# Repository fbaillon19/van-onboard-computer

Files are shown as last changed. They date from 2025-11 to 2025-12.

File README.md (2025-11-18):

# 🚐 VOBC - Van Onboard Computer

**V**an **O**nboard **B**oard **C**omputer - Système de monitoring et de gestion pour fourgon aménagé.





## 📋 Présentation

Le VOBC est un ordinateur de bord complet pour fourgon aménagé permettant de :
- 🌡️ Monitorer température intérieure/extérieure et humidité
- ⚡ Gérer l'énergie (batterie, panneaux solaires, consommation)
- ⚠️ Détecter les dangers (CO, fuite de gaz)
- 📊 Mesurer l'horizontalité pour stationnement
- 💧 Surveiller les niveaux d'eau
- 🔔 Alertes sonores et visuelles configurables
- 📈 Historique des données sur carte SD

## 🎯 Fonctionnalités

### Phase 1 - INDISPENSABLE ✅
- [x] Température intérieure + humidité (BME280)
- [x] Température extérieure (DS18B20)
- [x] Détection CO (MQ-7)
- [x] Détection gaz GPL (MQ-2)
- [x] Monitoring batterie (INA226)
- [x] Horizontalité 3 axes (MPU6050)
- [x] Détection ouverture portes (Reed Switch)
- [x] Alertes visuelles (LED RGB) et sonores (Buzzer)
- [x] Affichage LCD 20x4 I2C
- [x] Navigation par encodeur rotatif

### Phase 2 - IMPORTANTE 🔶
- [ ] Niveaux réservoirs eau (HC-SR04)
- [ ] Ventilation automatique (Module relais)
- [ ] Détecteur de mouvement (PIR)
- [ ] Monitoring panneaux solaires (INA226 #2)
- [ ] Éclairage automatique (LDR)

### Phase 3 - MOYENNE 🔹
- [ ] Horodatage (RTC DS3231)
- [ ] Historique données (Module SD)
- [ ] Orientation/boussole (HMC5883L)
- [ ] Prévision solaire algorithmique
- [ ] Interface Web/Bluetooth (optionnel)

## 🔧 Matériel

### Contrôleur
- Arduino MEGA 2560 R3

### Capteurs Phase 1
- BME280 (I2C) - Température + Humidité + Pression
- INA226 (I2C) - Courant/Tension batterie
- MPU6050 (I2C) - Gyroscope + Accéléromètre
- MQ-7 (Analogique) - Détecteur CO
- MQ-2 (Analogique) - Détecteur GPL/Butane
- DS18B20 (One-Wire) - Température extérieure étanche
- Reed Switch - Détection portes

### Interface
- LCD 20x4 avec module I2C
- Encodeur rotatif KY-040
- LED RGB + Buzzer piézo

### Alimentation
- Convertisseur DC-DC 12V → 5V (LM2596/MP1584) 3A min

Voir [HARDWARE.md](docs/HARDWARE.md) pour détails complets.

## 📁 Structure du projet

```
.
├── README.md                    # Ce fichier
├── LICENSE                      # Licence MIT
├── CHANGELOG.md                 # Historique des versions
├── docs/                        # Documentation
│   ├── HARDWARE.md             # Schémas et câblage
│   ├── SOFTWARE.md             # Architecture logicielle
│   ├── CONFIGURATION.md        # Configuration système
│   ├── INSTALL.md              # Guide d'installation
│   └── images/                 # Schémas et photos
├── firmware/                    # Code Arduino
│   └── van_onboard_computer/
│       ├── van_onboard_computer.ino  # Fichier principal
│       ├── config.h                   # Configuration
│       └── *.cpp/*.h                  # Modules
├── hardware/                    # Fichiers matériels
│   ├── schematics/             # Schémas électriques
│   ├── pcb/                    # PCB (phase finale)
│   └── datasheets/             # Datasheets composants
├── testing/                     # Tests unitaires
│   ├── test_codes/             # Codes de test capteurs
│   └── testing_README.md       # Guide de test
└── tools/                       # Outils et scripts
    └── scripts/                # Scripts utilitaires
```

## 🚀 Installation rapide

### Prérequis
- Arduino IDE 2.x
- Librairies (voir [INSTALL.md](docs/INSTALL.md))

### Étapes
```bash
# Cloner le repo
git clone https://github.com/[votre-username]/van-onboard-computer.git
cd van-onboard-computer

# Installer les librairies nécessaires
# (voir docs/INSTALL.md)

# Ouvrir le firmware
# Arduino IDE: Ouvrir firmware/van_onboard_computer/van_onboard_computer.ino
# PlatformIO: Ouvrir le dossier dans VS Code

# Configurer dans config.h
# Compiler et uploader sur Arduino MEGA
```

## 📚 Documentation

- [Guide matériel](docs/HARDWARE.md) - Schémas de câblage complets
- [Architecture logicielle](docs/SOFTWARE.md) - Structure du code
- [Configuration](docs/CONFIGURATION.md) - Paramétrage système
- [Installation](docs/INSTALL.md) - Guide d'installation pas à pas
- [Tests](testing/testing_README.md) - Procédures de test

## 🧪 Tests

Chaque capteur dispose de son code de test unitaire dans `testing/test_codes/`. Voir [testing_README.md](testing/testing_README.md) pour la procédure complète.

## 🤝 Contribution

Les contributions sont bienvenues ! 

1. Fork le projet
2. Créer une branche (`git checkout -b feature/amelioration`)
3. Commit (`git commit -am 'Ajout fonctionnalité'`)
4. Push (`git push origin feature/amelioration`)
5. Créer une Pull Request

## 📝 Changelog

Voir [CHANGELOG.md](CHANGELOG.md) pour l'historique des versions.

## 📄 Licence

Ce projet est sous licence MIT - voir [LICENSE](LICENSE) pour plus de détails.

## 👤 Auteur

**Frédéric BAILLON**
- GitHub: [@fbaillon19](https://github.com/fbaillon19)

## 🙏 Remerciements

- Communauté Arduino
- Fabricants de capteurs (Bosch, Texas Instruments, etc.)
- Tous les contributeurs du projet

## 📸 Galerie

_Photos à venir lors de l'installation..._

---

⭐ Si ce projet vous aide, n'hésitez pas à lui donner une étoile !

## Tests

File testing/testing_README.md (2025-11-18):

# Guide de test VOBC

## 📋 Présentation

Ce dossier contient tous les codes de test unitaires pour valider chaque capteur et composant individuellement avant l'intégration dans le système complet.

## 🎯 Objectif

Tester chaque composant séparément permet de :
- Vérifier le bon fonctionnement matériel
- Valider le câblage
- Comprendre le comportement de chaque capteur
- Identifier les problèmes rapidement
- Calibrer les capteurs si nécessaire

## 📁 Structure

```
testing/
├── test_codes/
│   ├── test_arduino/          # Test basique Arduino
│   ├── test_button/           # Test encodeur rotatif
│   ├── test_bme280/           # Test température/humidité
│   ├── test_mpu6050/          # Test gyroscope/accéléromètre
│   ├── test_ina226/           # Test mesure courant/tension
│   ├── test_mq7_mq2/          # Test détecteurs gaz
│   ├── test_ds18b20/          # Test température extérieure
│   ├── test_lcd/              # Test affichage LCD
│   ├── test_reed_switch/      # Test détection porte
│   ├── test_buzzer/           # Test alarme sonore
│   ├── test_led_rgb/          # Test LED RGB
│   └── test_encoder/          # Test encodeur rotatif
└── testing_README.md          # Ce fichier
```

## 🔧 Procédure de test recommandée

### 1. Test Arduino de base
**Fichier:** `test_codes/test_arduino/test_arduino.ino`

Valide que l'Arduino MEGA fonctionne correctement.
- Upload du code
- Vérification LED intégrée
- Test moniteur série

### 2. Test Scanner I2C
**Fichier:** `test_codes/test_i2c_scanner/test_i2c_scanner.ino`

Détecte tous les périphériques I2C connectés.
- Affiche les adresses I2C trouvées
- Permet d'identifier les capteurs

### 3. Tests capteurs individuels

Tester dans cet ordre :

#### a) BME280 (Température/Humidité)
**Fichier:** `test_codes/test_bme280/test_bme280.ino`
- Vérifier température ambiante cohérente
- Vérifier humidité 30-70%
- Tester réactivité (souffler dessus)

#### b) MPU6050 (Horizontalité)
**Fichier:** `test_codes/test_mpu6050/test_mpu6050.ino`
- Calibration obligatoire
- Vérifier angles Roll/Pitch sur surface plane
- Tester inclinaison

#### c) INA226 (Courant/Tension)
**Fichier:** `test_codes/test_ina226/test_ina226.ino`
- Mesure tension batterie
- Test avec charge connue
- Vérifier calcul puissance

#### d) DS18B20 (Température extérieure)
**Fichier:** `test_codes/test_ds18b20/test_ds18b20.ino`
- Vérifier température
- Tester réactivité
- Si étanche: test immersion

#### e) MQ-7 et MQ-2 (Détecteurs gaz)
**Fichier:** `test_codes/test_mq7_mq2/test_mq7_mq2.ino`
- ⚠️ ATTENTION: Préchauffage 24-48h première utilisation
- ⚠️ EXTÉRIEUR ou zone très ventilée
- Noter valeurs de base
- Tester réactivité

#### f) LCD I2C
**Fichier:** `test_codes/test_lcd/test_lcd.ino`
- Test affichage 4 lignes
- Réglage contraste
- Test rétroéclairage
- Test caractères spéciaux

#### g) Reed Switch
**Fichier:** `test_codes/test_reed_switch/test_reed_switch.ino`
- Test détection aimant
- Vérifier debouncing
- Test distance activation

#### h) Buzzer
**Fichier:** `test_codes/test_buzzer/test_buzzer.ino`
- Test différentes fréquences
- Test volume
- Test séquences alarme

#### i) LED RGB
**Fichier:** `test_codes/test_led_rgb/test_led_rgb.ino`
- Test couleurs primaires (R,G,B)
- Test couleurs mixtes (Jaune, Cyan, Magenta, Blanc)
- Test PWM (fade)

#### j) Encodeur rotatif
**Fichier:** `test_codes/test_encoder/test_encoder.ino`
- Test rotation (sens horaire/anti-horaire)
- Test bouton poussoir
- Test interruptions

## ⚠️ Sécurité

### Capteurs de gaz (MQ-7, MQ-2)
- **JAMAIS** tester en intérieur fermé
- Toujours en extérieur ou zone très ventilée
- Préchauffage minimum 24h avant mesures fiables
- Ne pas toucher (150°C en fonctionnement)

### Alimentation
- Vérifier polarités
- Commencer par alimentation USB (5V sécurisé)
- Tester convertisseur 12V→5V avec multimètre AVANT connexion

### Câblage
- Toujours débrancher avant modification
- Vérifier pas de court-circuit
- Respecter tensions (3.3V vs 5V)

## 📊 Tableau de suivi des tests

| Composant | Test OK | Date | Notes |
|---|---|---|---|
| Arduino MEGA | ☐ | | |
| I2C Scanner | ☐ | | Adresses détectées: |
| BME280 | ☐ | | |
| MPU6050 | ☐ | | Calibré: ☐ |
| INA226 #1 | ☐ | | |
| MQ-7 | ☐ | | Préchauffé: ☐ Valeur base: |
| MQ-2 | ☐ | | Préchauffé: ☐ Valeur base: |
| DS18B20 | ☐ | | |
| LCD I2C | ☐ | | Contraste OK: ☐ |
| Reed Switch | ☐ | | |
| Buzzer | ☐ | | |
| LED RGB | ☐ | | |
| Encodeur | ☐ | | |

## 📝 Rapport de test

Pour chaque test, noter :
- ✅ Succès / ❌ Échec
- Valeurs mesurées (si applicable)
- Problèmes rencontrés
- Solutions apportées

## 🔄 Prochaine étape

Une fois tous les tests unitaires validés :
1. Tester combinaisons de 2-3 capteurs
2. Vérifier pas de conflit I2C
3. Tester système complet
4. Calibration finale
5. Installation dans véhicule

## 💡 Conseils

- Tester un composant à la fois
- Noter toutes les observations
- Prendre photos du câblage fonctionnel
- Conserver les valeurs de calibration
- Documenter les problèmes résolus

---

**Temps estimé:** 4-6 heures pour tous les tests

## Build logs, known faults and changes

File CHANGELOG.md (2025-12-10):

# CHANGELOG - Tests matériels

## [2024-12-10] Session de debug et simplification

### ✅ Corrections appliquées

#### **KY040 (Encodeur rotatif)**
- **v2.1.0** : Correction comptage (1 clic = 1 position au lieu de 2)
- Ajout filtre anti-rebond logiciel (2ms) pour réduire bruit capacitif
- Passage aux interruptions matérielles (méthode ultra-fiable)
- Alternative proposée : intégration librairie Paul Stoffregen

#### **BME280 (Température/Humidité/Pression)**
- **v1.0.1** : FIX critique - Ajout paramètre `&Wire` dans `bme.begin()`
- Ajout méthodes manquantes : `hasCondensationRisk()`, `getSeaLevelPressure()`
- Ajout délais stabilisation (10ms, 50ms)
- Programme diagnostic bas niveau créé (`diagnostic_bme280.ino`)
- **Note** : Composant testé = BMP280 (pas d'humidité), BME280 commandé

#### **MPU6050 (Horizontalité)**
- **v2.0.0** : Simplification majeure - Accéléromètre uniquement
- Suppression gyroscope (cause de dérive thermique 5-12°)
- Lecture I2C directe (plus de dépendance à MPU6050_tockn)
- Filtre passe-bas exponentiel simple (alpha = 0.3)
- Calibration sur plan horizontal (800 échantillons)
- Dérive finale : < 2° (vs 12° avant) ✓
- Code réduit de ~300 lignes, plus maintenable

### 📚 Fichiers modifiés

```
testing/test_codes/
├── test_ky040/
│   └── KY040Encoder.h (v2.1.0)
├── test_bme280/
│   ├── BME280Sensor.h (v1.0.1)
│   └── diagnostic_bme280.ino (nouveau)
└── test_mpu6050/
    ├── MPU6050Sensor.h (v2.0.0 - refonte complète)
    └── test_mpu6050.ino (v2.0.0 - simplifié)
```

### 🎯 Philosophie de conception

**Avant** : Code "apprendre le module", complexe, features inutiles
**Maintenant** : Code pragmatique focalisé sur le BESOIN RÉEL

- MPU6050 : Juste mesurer horizontalité (pas besoin gyroscope)
- Tests : Valider "ça marche pour mon projet", pas "apprendre le module"
- Simplicité : Moins de code = moins de bugs = plus maintenable

### 📊 Statut des tests

| Test | Statut | Notes |
|---|---|---|
| test_arduino | ✅ OK | - |
| test_bme280 | ⏸️ Attente matériel | BMP280 détecté, BME280 commandé |
| test_buzzer | ⏸️ Attente PN2222 | Transistor manquant |
| test_ds18b20 | ✅ OK | - |
| test_ina226 | ⏳ À faire | Test sur PCB préféré |
| test_ky040 | ✅ OK | Condensateurs 100nF ajoutés |
| test_lcd | ✅ OK | - |
| test_led_rgb | ⏳ À faire | - |
| test_mpu6050 | ✅ OK | Refonte complète |
| test_mq2 | ⏳ À faire | - |
| test_mq7 | ⏳ À faire | - |

**Progression** : 6/11 tests validés (55%)

### 🔧 Améliorations matérielles

- **KY040** : Ajout de 2 condensateurs 100nF (CLK-GND, DT-GND) pour filtrage bruit
- **MPU6050** : AD0 à GND confirmé (adresse 0x68)

### 📝 Documentation

- Ajout explications détaillées sur les offsets de calibration (MPU6050)
- Diagrammes de décision pour choix des outils (encodeur)
- Comparaisons avant/après pour justifier les simplifications

### 🚀 Prochaines étapes

1. Réception BME280 → test_bme280 complet
2. Réception PN2222 → test_buzzer
3. Tests restants : LED RGB, MQ2, MQ7
4. Test INA226 sur PCB assemblé
5. Tests recommandés : test_relays, test_integration

---

**Résumé** : Session très productive avec 3 corrections majeures. Code plus simple, plus fiable, mieux documenté. Approche pragmatique validée.

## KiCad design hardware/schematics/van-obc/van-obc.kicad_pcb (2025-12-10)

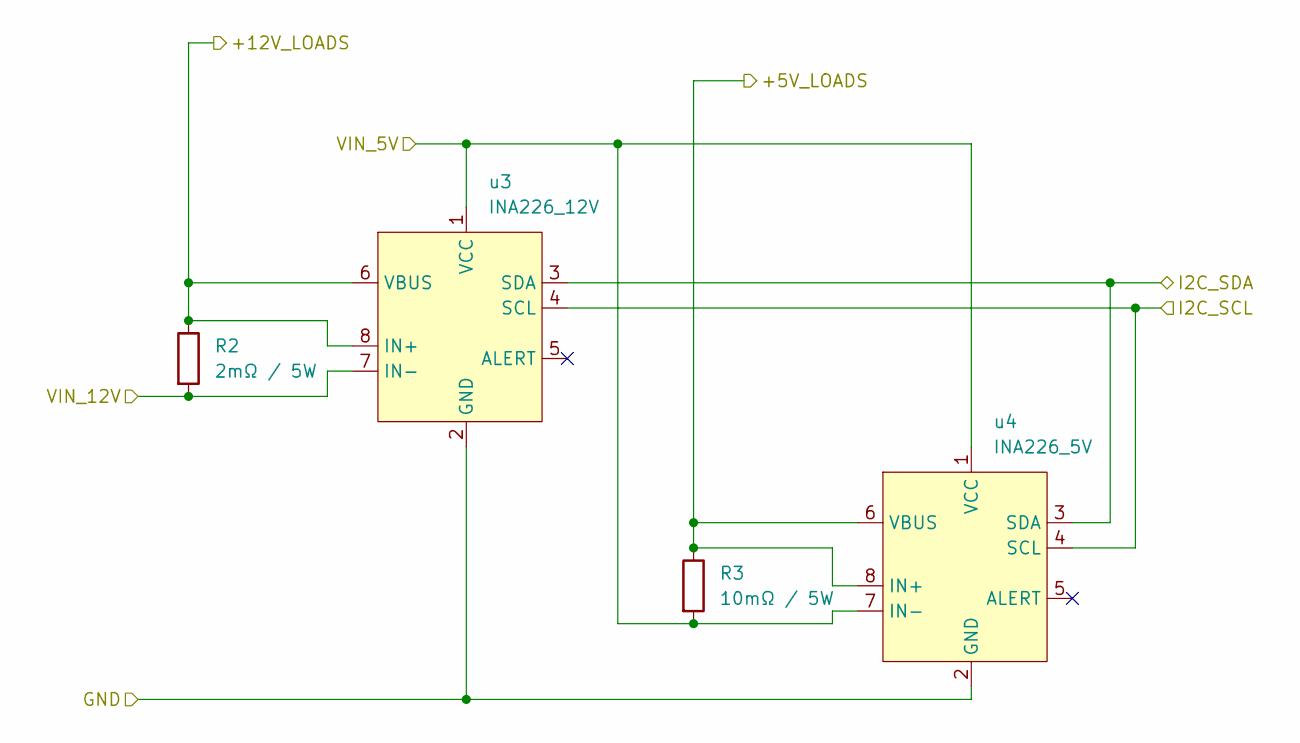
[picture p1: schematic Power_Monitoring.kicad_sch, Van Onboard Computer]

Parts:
R2: 2mΩ / 5W; R_2512_6332Metric
R3: 10mΩ / 5W; R_2512_6332Metric
u3: INA226_12V; INA226_Module_Header_1x08
u4: INA226_5V; INA226_Module_Header_1x08

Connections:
/Display_And_UI/+5V: R3.1, u4.6 (VBUS), u4.8 (IN+); also elsewhere on the board
/Display_And_UI/GND: u3.2 (GND), u4.2 (GND); also elsewhere on the board
/Display_And_UI/I2C_SCL: u3.4 (SCL), u4.4 (SCL); also elsewhere on the board
/Display_And_UI/I2C_SDA: u3.3 (SDA), u4.3 (SDA); also elsewhere on the board
/Power_Input/+5V_PROT: R3.2, u3.1 (VCC), u4.1 (VCC), u4.7 (IN-); also elsewhere on the board
/Power_Input/+12V: R2.1, u3.6 (VBUS), u3.8 (IN+); also elsewhere on the board
/Power_Input/+12V_PROT: R2.2, u3.7 (IN-); also elsewhere on the board

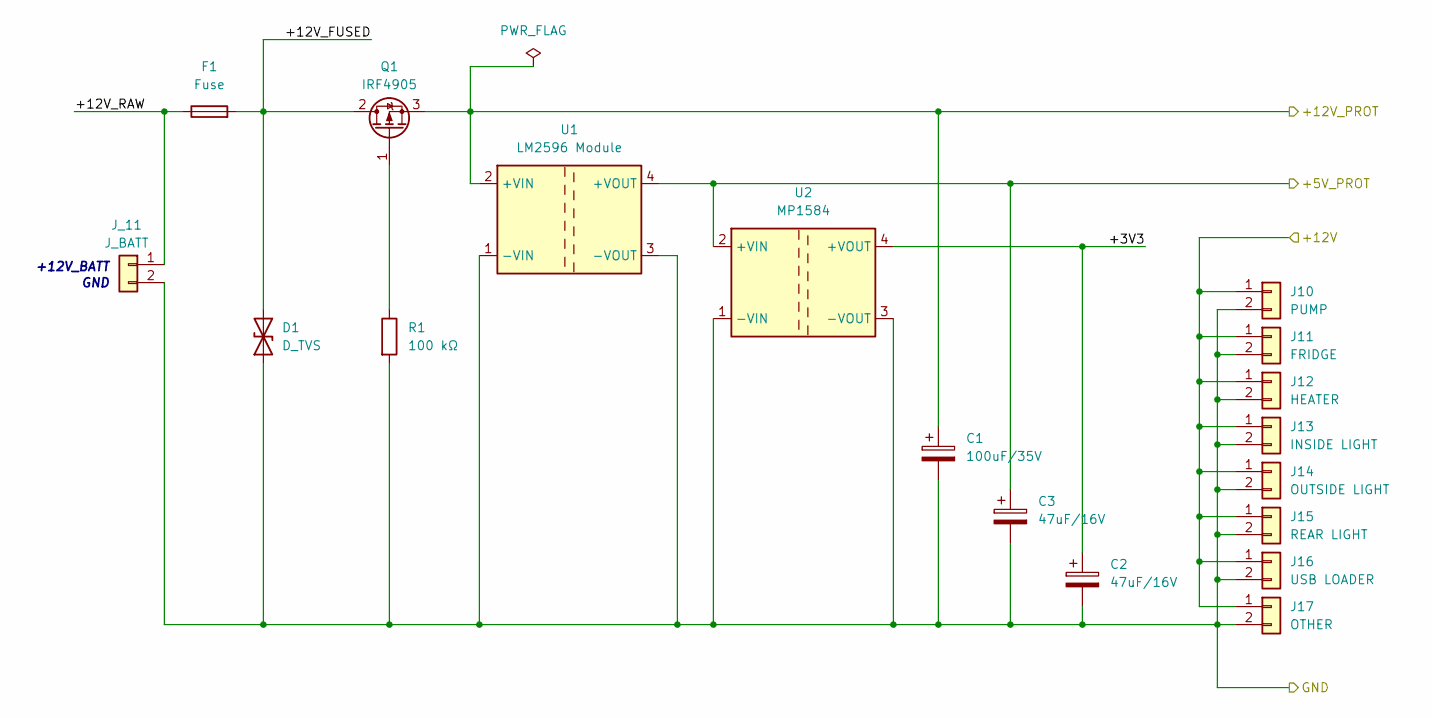
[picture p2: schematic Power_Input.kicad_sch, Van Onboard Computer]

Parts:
C1: 100uF/35V; CP_Radial_D8.0mm_P3.50mm
C2, C3: 47uF/16V; CP_Radial_D6.3mm_P2.50mm
D1: D_TVS; D_SMA-SMB_Universal_Handsoldering
F1: Fuse; Fuseholder_Clip-5x20mm_Bel_FC-203-22_Lateral_P17.80x5.00mm_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
J10: PUMP; Connecteur 2 vis
J11: FRIDGE; Connecteur 2 vis
J12: HEATER; Connecteur 2 vis
J13: INSIDE LIGHT; Connecteur 2 vis
J14: OUTSIDE LIGHT; Connecteur 2 vis
J15: REAR LIGHT; Connecteur 2 vis
J16: USB LOADER; Connecteur 2 vis
J17: OTHER; Connecteur 2 vis
J_11: J_BATT; Connecteur 2 vis
Q1: IRF4905; TO-220-3_Vertical
R1: 100 kΩ; R_Axial_DIN0207_L6.3mm_D2.5mm_P10.16mm_Horizontal
U1: LM2596 Module; LM2596_Breakout
U2: MP1584; MP1584_Breakout

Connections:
/Display_And_UI/GND: C1.2, C2.2, C3.2, D1.1 (A1), J10.2, J11.2, J12.2, J13.2, J14.2, J15.2, J16.2, J17.2, J_11.2, R1.2, U1.1 (-VIN), U1.3 (-VOUT), U2.1 (-VIN), U2.3 (-VOUT); also elsewhere on the board
/Power_Input/+3V3: C2.1, U2.4 (+VOUT)
/Power_Input/+5V_PROT: C3.1, U1.4 (+VOUT), U2.2 (+VIN); also elsewhere on the board
/Power_Input/+12V: J10.1, J11.1, J12.1, J13.1, J14.1, J15.1, J16.1, J17.1; also elsewhere on the board
/Power_Input/+12V_FUSED: D1.2 (A2), F1.2, Q1.2 (D)
/Power_Input/+12V_PROT: C1.1, Q1.3 (S), U1.2 (+VIN); also elsewhere on the board
/Power_Input/+12V_RAW: F1.1, J_11.1
unnamed: Q1.1 (G), R1.1

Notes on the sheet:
+12V_BATT
GND

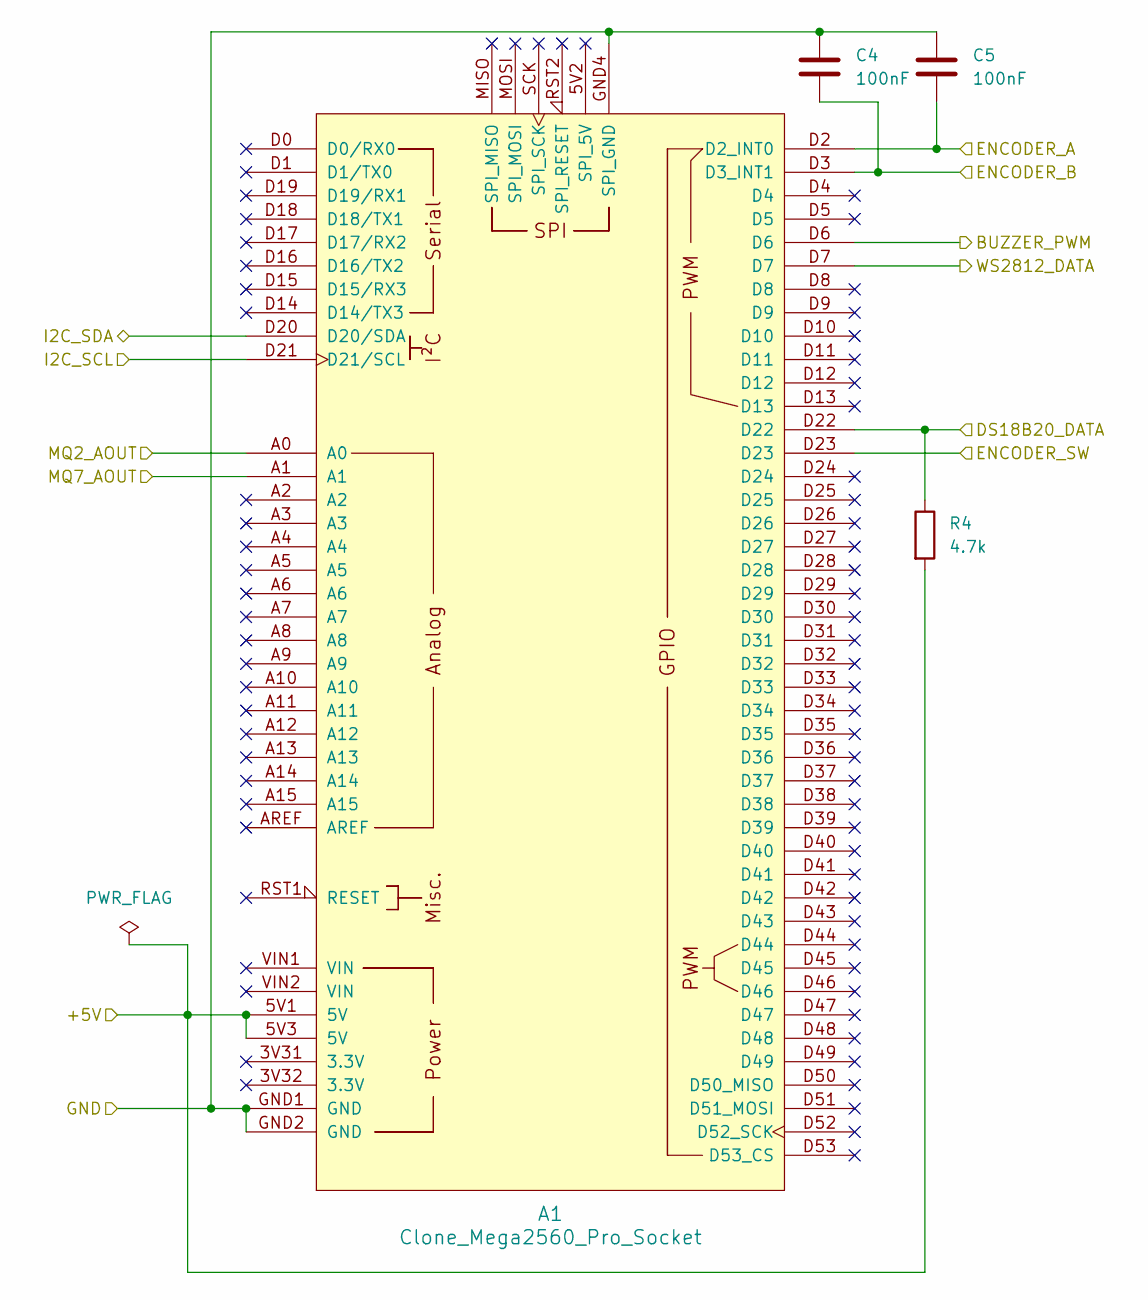
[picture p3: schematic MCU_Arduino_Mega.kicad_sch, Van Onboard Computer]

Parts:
A1: Clone_Mega2560_Pro_Socket
C4, C5: 100nF; C_Disc_D4.3mm_W1.9mm_P5.00mm
R4: 4.7k; R_Axial_DIN0207_L6.3mm_D2.5mm_P10.16mm_Horizontal

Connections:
/Display_And_UI/+5V: A1.5V1 (5V), A1.5V3 (5V), R4.2; also elsewhere on the board
/Display_And_UI/BUZZER_PWM: A1.D6; also elsewhere on the board
/Display_And_UI/ENCODER_A: A1.D2 (D2_INT0), C5.2; also elsewhere on the board
/Display_And_UI/ENCODER_B: A1.D3 (D3_INT1), C4.2; also elsewhere on the board
/Display_And_UI/ENCODER_SW: A1.D23; also elsewhere on the board
/Display_And_UI/GND: A1.GND1 (GND), A1.GND2 (GND), A1.GND4 (SPI_GND), C4.1, C5.1; also elsewhere on the board
/Display_And_UI/I2C_SCL: A1.D21 (D21/SCL); also elsewhere on the board
/Display_And_UI/I2C_SDA: A1.D20 (D20/SDA); also elsewhere on the board
/Display_And_UI/WS2812_DATA: A1.D7; also elsewhere on the board
/MCU_Arduino_Mega/DS18B20_DATA: A1.D22, R4.1; also elsewhere on the board
/MCU_Arduino_Mega/MQ2_AOUT: A1.A0; also elsewhere on the board
/MCU_Arduino_Mega/MQ7_AOUT: A1.A1; also elsewhere on the board

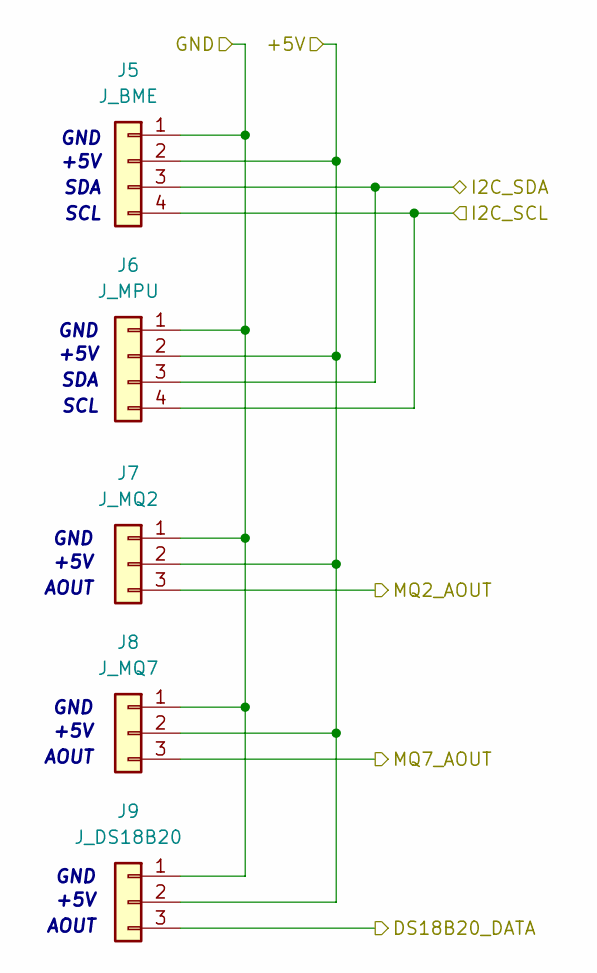
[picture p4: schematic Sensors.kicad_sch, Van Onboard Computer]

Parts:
J5: J_BME; PinHeader_1x04_P2.54mm_Vertical
J6: J_MPU; PinHeader_1x04_P2.54mm_Vertical
J7: J_MQ2; PinHeader_1x03_P2.54mm_Vertical
J8: J_MQ7; PinHeader_1x03_P2.54mm_Vertical
J9: J_DS18B20; PinHeader_1x03_P2.54mm_Vertical

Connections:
/Display_And_UI/+5V: J5.2, J6.2, J7.2, J8.2, J9.2; also elsewhere on the board
/Display_And_UI/GND: J5.1, J6.1, J7.1, J8.1, J9.1; also elsewhere on the board
/Display_And_UI/I2C_SCL: J5.4, J6.4; also elsewhere on the board
/Display_And_UI/I2C_SDA: J5.3, J6.3; also elsewhere on the board
/MCU_Arduino_Mega/DS18B20_DATA: J9.3; also elsewhere on the board
/MCU_Arduino_Mega/MQ2_AOUT: J7.3; also elsewhere on the board
/MCU_Arduino_Mega/MQ7_AOUT: J8.3; also elsewhere on the board

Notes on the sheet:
+5V
AOUT
GND
SCL
SDA

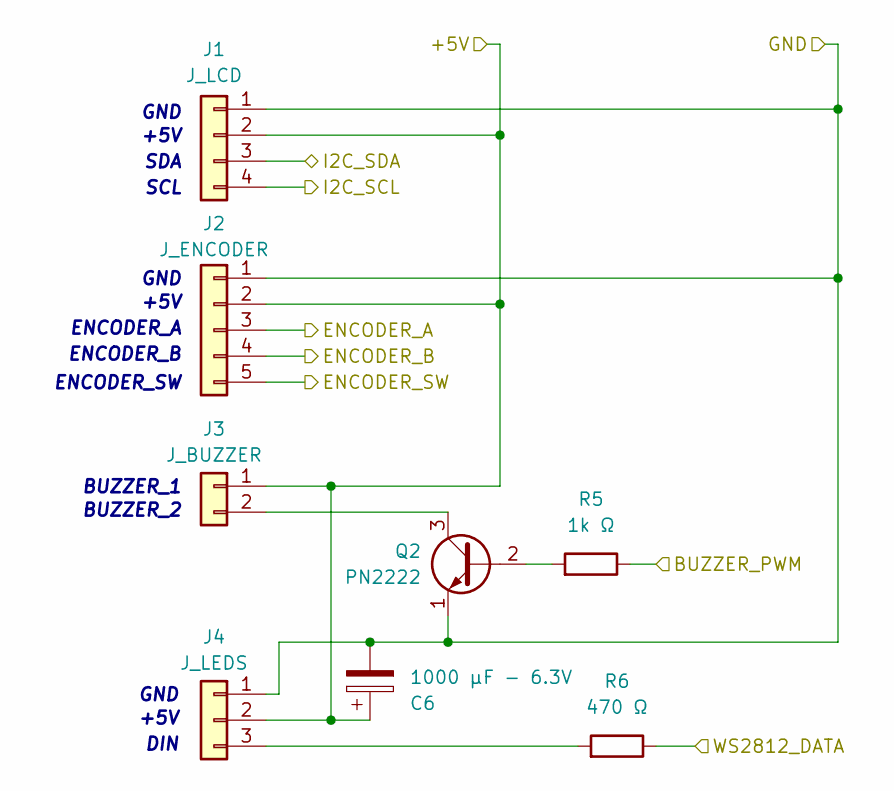
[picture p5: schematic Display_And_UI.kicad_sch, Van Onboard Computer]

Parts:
C6: 1000 µF - 6.3V; CP_Radial_D8.0mm_P3.50mm
J1: J_LCD; PinHeader_1x04_P2.54mm_Vertical
J2: J_ENCODER; PinHeader_1x05_P2.54mm_Vertical
J3: J_BUZZER; PinHeader_1x02_P2.54mm_Vertical
J4: J_LEDS; PinHeader_1x03_P2.54mm_Vertical
Q2: PN2222; TO-92_Inline
R5: 1k Ω; R_Axial_DIN0207_L6.3mm_D2.5mm_P10.16mm_Horizontal
R6: 470 Ω; R_Axial_DIN0207_L6.3mm_D2.5mm_P10.16mm_Horizontal

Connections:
/Display_And_UI/+5V: C6.1, J1.2, J2.2, J3.1, J4.2; also elsewhere on the board
/Display_And_UI/BUZZER_PWM: R5.1; also elsewhere on the board
/Display_And_UI/ENCODER_A: J2.3; also elsewhere on the board
/Display_And_UI/ENCODER_B: J2.4; also elsewhere on the board
/Display_And_UI/ENCODER_SW: J2.5; also elsewhere on the board
/Display_And_UI/GND: C6.2, J1.1, J2.1, J4.1, Q2.1 (E); also elsewhere on the board
/Display_And_UI/I2C_SCL: J1.4; also elsewhere on the board
/Display_And_UI/I2C_SDA: J1.3; also elsewhere on the board
/Display_And_UI/WS2812_DATA: R6.1; also elsewhere on the board
unnamed: J3.2, Q2.3 (C)
unnamed: J4.3, R6.2
unnamed: Q2.2 (B), R5.2

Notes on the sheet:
GND
+5V
SDA
ENCODER_A
ENCODER_SW
BUZZER_2
BUZZER_1
SCL
ENCODER_B
DIN

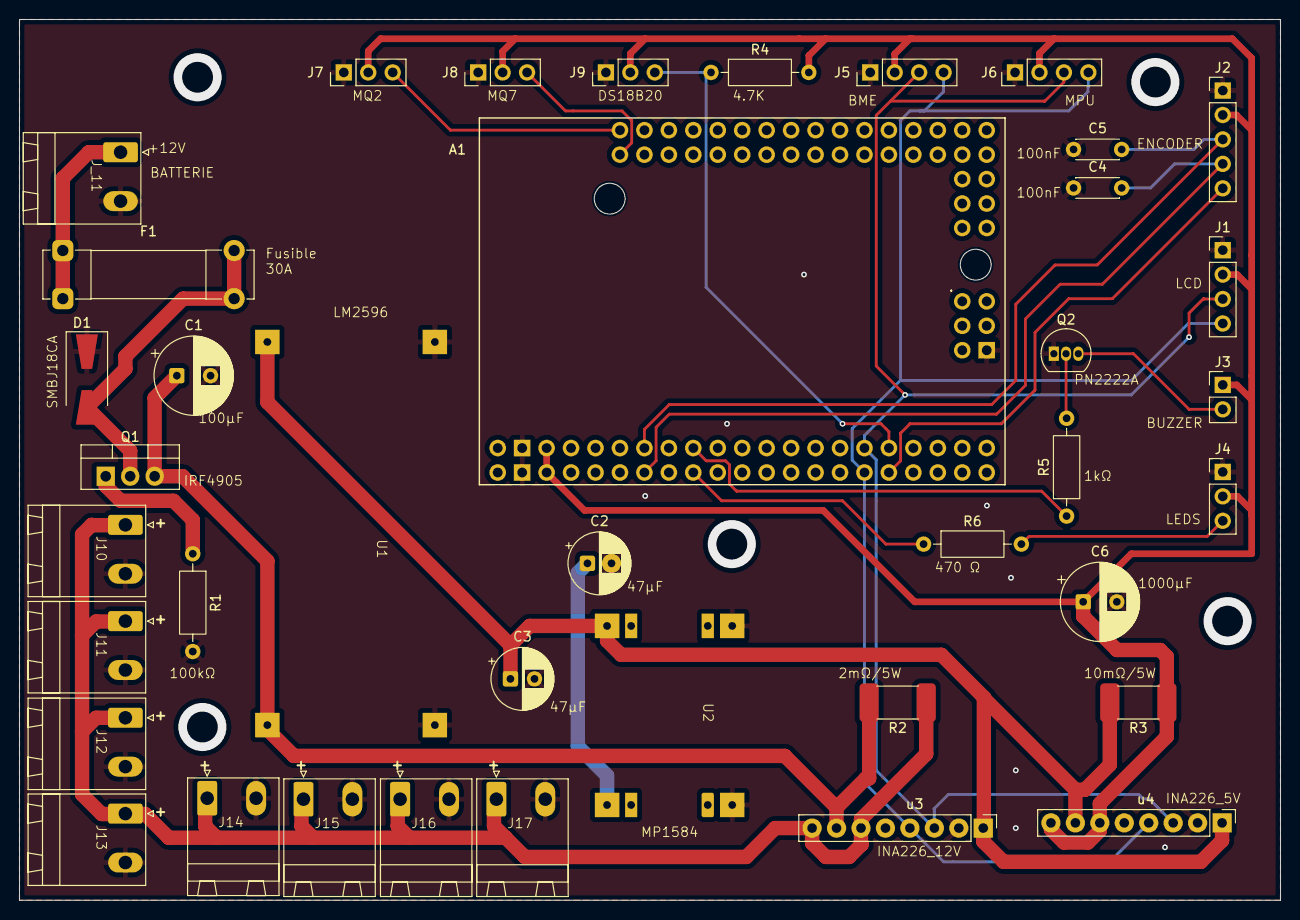
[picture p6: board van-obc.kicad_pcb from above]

Board: 2 copper layers, 131.0 x 91.5 mm, 39 parts (0 on the bottom side), 22 nets.

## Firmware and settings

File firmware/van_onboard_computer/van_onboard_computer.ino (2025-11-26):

/**
 * @file van_onboard_computer.ino
 * @brief Programme principal Van Onboard Computer
 * @author Frédéric BAILLON
 * @version 0.1.0
 * @date 2024-11-26
 * 
 * @details
 * Système de monitoring pour van aménagé (Renault Trafic)
 * Plateforme : Arduino Mega R3
 * 
 * Fonctionnalités :
 * - Surveillance environnement (températures, humidité, pression)
 * - Surveillance électrique (12V, 5V, courants, puissance)
 * - Détection gaz dangereux (CO, GPL, fumée)
 * - Horizontalité (inclinomètre MPU6050)
 * - Alertes hiérarchisées avec buzzer
 * - Affichage LCD 20x4 + Navigation encodeur
 * - Bandeau LED WS2812B (8 LEDs)
 * 
 * Modules :
 * - SensorManager : Acquisition capteurs
 * - AlertSystem : Gestion alertes
 * - LEDManager : Affichage LEDs
 * - DisplayManager : Affichage LCD + Navigation
 * 
 * @warning Priorité absolue à la sécurité (CO, GPL)
 * @note Pré-chauffage requis : MQ7 (3 min), MQ2 (1 min)
 */

// ============================================
// INCLUDES
// ============================================
#include <Wire.h>
#include "config.h"
#include "SystemData.h"
#include "SensorManager.h"
#include "AlertSystem.h"
#include "LEDManager.h"
#include "DisplayManager.h"

// ============================================
// ÉTAT SYSTÈME GLOBAL
// ============================================
SystemState systemState;

// ============================================
// GESTIONNAIRES
// ============================================
SensorManager* sensorManager = nullptr;
AlertSystem* alertSystem = nullptr;
LEDManager* ledManager = nullptr;
DisplayManager* displayManager = nullptr;

// ============================================
// TIMING
// ============================================
unsigned long loopStartTime = 0;
unsigned long loopCount = 0;
unsigned long lastStatsDisplay = 0;

// ============================================
// SETUP - INITIALISATION
// ============================================
void setup() {
  // Initialiser Serial pour debug
  #if USE_SERIAL_DEBUG
  Serial.begin(SERIAL_BAUD_RATE);
  while (!Serial && millis() < 3000); // Attendre max 3s

  Serial.println();
  Serial.println(F("===================================="));
  Serial.println(F("   VAN ONBOARD COMPUTER v" FIRMWARE_VERSION));
  Serial.println(F("   (c) 2024 Frederic BAILLON"));
  Serial.println(F("===================================="));
  Serial.println();
  #endif
  
  // Initialiser I2C
  Wire.begin();
  Wire.setClock(400000); // I2C Fast Mode (400 kHz)
  
  DEBUG_PRINTLN(F("I2C initialise (400 kHz)"));
  delay(100);
  
  // Initialiser état système
  initSystemState(systemState);
  systemState.uptime = 0;
  
  DEBUG_PRINTLN(F("Etat systeme initialise"));
  
  // ====================================
  // INITIALISATION GESTIONNAIRES
  // ====================================
  // 1. DisplayManager (premier pour afficher progression)
  DEBUG_PRINTLN(F("\n--- Initialisation Display ---"));
  displayManager = new DisplayManager(systemState);
  if (!displayManager->begin()) {
    DEBUG_PRINTLN(F("[ERREUR] Echec initialisation Display"));
  }
  delay(1000); // Laisser temps de lire écran boot
  
  // 2. SensorManager
  DEBUG_PRINTLN(F("\n--- Initialisation Capteurs ---"));
  if (systemState.sensors.lcd) {
    displayManager->showMessage("Init capteurs...", 0);
  }
  
  sensorManager = new SensorManager(systemState);
  if (!sensorManager->begin()) {
    DEBUG_PRINTLN(F("[ERREUR] Echec initialisation Capteurs"));
    if (systemState.sensors.lcd) {
      displayManager->showMessage("ERREUR CAPTEURS!", 3000);
    }
  }
  
  // 3. AlertSystem
  DEBUG_PRINTLN(F("\n--- Initialisation Alertes ---"));
  alertSystem = new AlertSystem(systemState);
  if (!alertSystem->begin()) {
    DEBUG_PRINTLN(F("[ERREUR] Echec initialisation Alertes"));
  }
  
  // 4. LEDManager
  DEBUG_PRINTLN(F("\n--- Initialisation LEDs ---"));
  ledManager = new LEDManager(systemState);
  if (!ledManager->begin()) {
    DEBUG_PRINTLN(F("[ERREUR] Echec initialisation LEDs"));
  }
  
  // Animation démarrage
  if (systemState.sensors.leds) {
    ledManager->bootAnimation();
  }
  
  // ====================================
  // RÉCAPITULATIF INITIALISATION
  // ====================================
  DEBUG_PRINTLN(F("\n===================================="));
  DEBUG_PRINTLN(F("RECAPITULATIF INITIALISATION"));
  DEBUG_PRINTLN(F("===================================="));
  
  uint8_t sensorCount = 0;
  
  DEBUG_PRINT(F("BME280 (temp/hum int): "));
  DEBUG_PRINTLN(systemState.sensors.bme280 ? F("OK") : F("ABSENT"));
  if (systemState.sensors.bme280) sensorCount++;
  
  DEBUG_PRINT(F("DS18B20 (temp ext):    "));
  DEBUG_PRINTLN(systemState.sensors.ds18b20 ? F("OK") : F("ABSENT"));
  if (systemState.sensors.ds18b20) sensorCount++;
  
  DEBUG_PRINT(F("MPU6050 (niveau):      "));
  DEBUG_PRINTLN(systemState.sensors.mpu6050 ? F("OK") : F("ABSENT"));
  if (systemState.sensors.mpu6050) sensorCount++;
  
  DEBUG_PRINT(F("MQ7 (CO):              "));
  DEBUG_PRINTLN(systemState.sensors.mq7 ? F("OK") : F("ABSENT"));
  if (systemState.sensors.mq7) sensorCount++;
  
  DEBUG_PRINT(F("MQ2 (GPL/fumee):       "));
  DEBUG_PRINTLN(systemState.sensors.mq2 ? F("OK") : F("ABSENT"));
  if (systemState.sensors.mq2) sensorCount++;
  
  DEBUG_PRINT(F("INA226 12V:            "));
  DEBUG_PRINTLN(systemState.sensors.ina226_12v ? F("OK") : F("ABSENT"));
  if (systemState.sensors.ina226_12v) sensorCount++;
  
  DEBUG_PRINT(F("INA226 5V:             "));
  DEBUG_PRINTLN(systemState.sensors.ina226_5v ? F("OK") : F("ABSENT"));
  if (systemState.sensors.ina226_5v) sensorCount++;
  
  DEBUG_PRINT(F("LCD 20x4:              "));
  DEBUG_PRINTLN(systemState.sensors.lcd ? F("OK") : F("ABSENT"));
  
  DEBUG_PRINT(F("Encodeur KY040:        "));
  DEBUG_PRINTLN(systemState.sensors.encoder ? F("OK") : F("ABSENT"));
  
  DEBUG_PRINT(F("LEDs WS2812B:          "));
  DEBUG_PRINTLN(systemState.sensors.leds ? F("OK") : F("ABSENT"));
  
  DEBUG_PRINT(F("Buzzer:                "));
  DEBUG_PRINTLN(systemState.sensors.buzzer ? F("OK") : F("ABSENT"));
  
  DEBUG_PRINTLN(F("===================================="));
  DEBUG_PRINTF("Total capteurs actifs: %d/7\n", sensorCount);
  DEBUG_PRINTLN(F("====================================\n"));
  
  // Vérifier qu'au moins les capteurs critiques sont présents
  if (!systemState.sensors.mq7 || !systemState.sensors.mq2) {
    DEBUG_PRINTLN(F("[ALERTE] Capteurs gaz manquants - Securite compromise!"));
    if (systemState.sensors.lcd) {
      displayManager->showMessage("ALERTE: GAZ!", 3000);
    }
  }
  
  // Mode pré-chauffage
  if (systemState.sensors.mq7 || systemState.sensors.mq2) {
    DEBUG_PRINTLN(F("\n=== DEMARRAGE PRE-CHAUFFE ==="));
    DEBUG_PRINTLN(F("MQ7: 180 secondes"));
    DEBUG_PRINTLN(F("MQ2: 60 secondes"));
    DEBUG_PRINTLN(F("Merci de patienter..."));
    DEBUG_PRINTLN(F("================================\n"));
  }
  
  // Système prêt
  systemState.initialized = true;
  
  DEBUG_PRINTLN(F("=== SYSTEME PRET ===\n"));
  
  // Marquer temps de démarrage
  loopStartTime = millis();
}

// ============================================
// LOOP - BOUCLE PRINCIPALE
// ============================================
void loop() {
  unsigned long loopStart = millis();
  
  // ====================================
  // 1. ACQUISITION CAPTEURS
  // ====================================
  // Chaque capteur gère son propre intervalle
  if (sensorManager) {
    sensorManager->update();
  }
  
  // ====================================
  // 2. VÉRIFICATION ALERTES
  // ====================================
  // PRIORITÉ ABSOLUE - Vérifié à chaque cycle
  if (alertSystem) {
    alertSystem->checkAlerts();
    alertSystem->updateBuzzer();
  }
  
  // ====================================
  // 3. MISE À JOUR LEDS
  // ====================================
  if (ledManager) {
    // Animation spéciale pendant pré-chauffage
    if (systemState.mode == SystemMode::MODE_PREHEAT && sensorManager) {
      uint8_t percent = sensorManager->getPreheatPercent();
      ledManager->preheatAnimation(percent);
    } else {
      ledManager->update();
    }
  }
  
  // ====================================
  // 4. MISE À JOUR AFFICHAGE
  // ====================================
  if (displayManager) {
    displayManager->update();
    displayManager->handleScreenTimeout();
  }
  
  // ====================================
  // 5. GESTION CALIBRATION MPU6050
  // ====================================
  if (systemState.calibrationMode) {
    performMPU6050Calibration();
  }
  
  // ====================================
  // 6. MISE À JOUR UPTIME
  // ====================================
  systemState.uptime = millis() / 1000; // En secondes
  
  // ====================================
  // 7. STATISTIQUES DEBUG (toutes les 10s)
  // ====================================
  #if USE_SERIAL_DEBUG
  if (millis() - lastStatsDisplay >= 10000) {
    lastStatsDisplay = millis();
    displayStats();
  }
  #endif
  
  // ====================================
  // 8. WATCHDOG / MONITORING LOOP
  // ====================================
  loopCount++;
  unsigned long loopDuration = millis() - loopStart;
  
  // Avertir si loop trop lent (>100ms)
  if (loopDuration > 100) {
    DEBUG_PRINTF("[WARNING] Loop lent: %lu ms\n", loopDuration);
  }
  
  // Petit délai pour stabilité (optionnel)
  // delay(1); // Décommenter si nécessaire
}

// ============================================
// FONCTIONS AUXILIAIRES
// ============================================
/**
 * @brief Effectue la calibration du MPU6050
 * 
 * @details
 * - Affiche instructions sur LCD
 * - Effectue 100 mesures
 * - Calcule et applique offsets
 * - Affiche résultat
 */
void performMPU6050Calibration() {
  systemState.calibrationMode = false; // Reset flag
  
  if (!systemState.sensors.mpu6050 || !sensorManager) {
    if (displayManager) {
      displayManager->showMessage("MPU6050 absent!", 2000);
    }
    return;
  }
  
  DEBUG_PRINTLN(F("\n=== CALIBRATION MPU6050 ==="));
  DEBUG_PRINTLN(F("Placez le van a plat et immobile"));
  DEBUG_PRINTLN(F("Calibration en cours..."));
  
  // Afficher message LCD
  if (displayManager && systemState.sensors.lcd) {
    displayManager->showMessage("Calibration MPU...", 0);
    delay(1000);
    displayManager->showMessage("Van a plat!", 2000);
  }
  
  // Callback progression
  auto progressCallback = [](uint16_t current, uint16_t total) {
    if (current % 10 == 0) { // Afficher tous les 10 échantillons
      DEBUG_PRINTF("  %d/%d\n", current, total);
    }
  };
  
  // Lancer calibration
  bool success = sensorManager->calibrateMPU6050(progressCallback);
  
  if (success) {
    DEBUG_PRINTLN(F("Calibration reussie!"));
    
    float roll, pitch;
    sensorManager->getMPU6050Offsets(roll, pitch);
    DEBUG_PRINTF("Offsets: Roll=%.2f, Pitch=%.2f\n", roll, pitch);
    
    if (displayManager) {
      displayManager->showMessage("Calibration OK!", 2000);
    }
  } else {
    DEBUG_PRINTLN(F("Echec calibration!"));
    
    if (displayManager) {
      displayManager->showMessage("Echec calib!", 2000);
    }
  }
  
  DEBUG_PRINTLN(F("=========================\n"));
  
  // Retour écran précédent
  if (displayManager) {
    displayManager->forceRefresh();
  }
}

/**
 * @brief Affiche les statistiques système sur Serial
 */
void displayStats() {
  DEBUG_PRINTLN(F("\n===================================="));
  DEBUG_PRINTLN(F("STATISTIQUES SYSTEME"));
  DEBUG_PRINTLN(F("===================================="));
  
  // Uptime
  unsigned long uptimeSeconds = systemState.uptime;
  unsigned long hours = uptimeSeconds / 3600;
  unsigned long minutes = (uptimeSeconds % 3600) / 60;
  unsigned long seconds = uptimeSeconds % 60;
  DEBUG_PRINTF("Uptime: %02lu:%02lu:%02lu\n", hours, minutes, seconds);
  
  // Mode
  DEBUG_PRINT(F("Mode: "));
  DEBUG_PRINTLN(systemModeToString(systemState.mode));
  
  // Ecran
  DEBUG_PRINT(F("Ecran: "));
  DEBUG_PRINTLN(screenToString(systemState.currentScreen));
  
  // Environnement
  DEBUG_PRINTLN(F("\n--- ENVIRONNEMENT ---"));
  if (systemState.environment.tempIntValid) {
    DEBUG_PRINTF("Temp int: %.1f C\n", systemState.environment.tempInterior);
  }
  if (systemState.environment.tempExtValid) {
    DEBUG_PRINTF("Temp ext: %.1f C\n", systemState.environment.tempExterior);
  }
  if (systemState.environment.humidityValid) {
    DEBUG_PRINTF("Humidite: %.0f %%\n", systemState.environment.humidity);
  }
  if (systemState.environment.pressureValid) {
    DEBUG_PRINTF("Pression: %.0f hPa\n", systemState.environment.pressure);
  }
  
  // Puissance
  DEBUG_PRINTLN(F("\n--- ENERGIE ---"));
  if (systemState.power.voltage12VValid) {
    DEBUG_PRINTF("12V: %.2f V - %.2f A - %.1f W\n",
                 systemState.power.voltage12V,
                 systemState.power.current12V,
                 systemState.power.power12V);
  }
  if (systemState.power.voltage5VValid) {
    DEBUG_PRINTF("5V: %.2f V - %.2f A - %.1f W\n",
                 systemState.power.voltage5V,
                 systemState.power.current5V,
                 systemState.power.power5V);
  }
  DEBUG_PRINTF("Total: %.1f W\n", systemState.power.powerTotal);
  
  // Sécurité
  DEBUG_PRINTLN(F("\n--- SECURITE ---"));
  if (systemState.safety.mq7Preheated) {
    DEBUG_PRINTF("CO:    %.0f ppm", systemState.safety.coPPM);
    if (systemState.safety.coPPM > CO_THRESHOLD_DANGER) {
      DEBUG_PRINTLN(F(" [DANGER]"));
    } else if (systemState.safety.coPPM > CO_THRESHOLD_WARNING) {
      DEBUG_PRINTLN(F(" [WARNING]"));
    } else {
      DEBUG_PRINTLN(F(" [OK]"));
    }
  } else {
    DEBUG_PRINTLN(F("CO:    [PRE-CHAUFFE]"));
  }
  
  if (systemState.safety.mq2Preheated) {
    DEBUG_PRINTF("GPL:   %.0f ppm", systemState.safety.gplPPM);
    if (systemState.safety.gplPPM > GPL_THRESHOLD_DANGER) {
      DEBUG_PRINTLN(F(" [DANGER]"));
    } else if (systemState.safety.gplPPM > GPL_THRESHOLD_WARNING) {
      DEBUG_PRINTLN(F(" [WARNING]"));
    } else {
      DEBUG_PRINTLN(F(" [OK]"));
    }
    
    DEBUG_PRINTF("Fumee: %.0f ppm", systemState.safety.smokePPM);
    if (systemState.safety.smokePPM > SMOKE_THRESHOLD_DANGER) {
      DEBUG_PRINTLN(F(" [DANGER]"));
    } else if (systemState.safety.smokePPM > SMOKE_THRESHOLD_WARNING) {
      DEBUG_PRINTLN(F(" [WARNING]"));
    } else {
      DEBUG_PRINTLN(F(" [OK]"));
    }
  } else {
    DEBUG_PRINTLN(F("GPL:   [PRE-CHAUFFE]"));
    DEBUG_PRINTLN(F("Fumee: [PRE-CHAUFFE]"));
  }
  
  // Horizontalité
  DEBUG_PRINTLN(F("\n--- HORIZONTALITE ---"));
  if (systemState.level.valid) {
    DEBUG_PRINTF("Roll:  %+.1f deg\n", systemState.level.roll);
    DEBUG_PRINTF("Pitch: %+.1f deg\n", systemState.level.pitch);
    DEBUG_PRINTF("Total: %.1f deg", systemState.level.totalTilt);
    if (systemState.level.totalTilt > TILT_DANGER) {
      DEBUG_PRINTLN(F(" [DANGER]"));
    } else if (systemState.level.totalTilt > TILT_WARNING) {
      DEBUG_PRINTLN(F(" [WARNING]"));
    } else {
      DEBUG_PRINTLN(F(" [OK]"));
    }
  }
  
  // Alertes
  DEBUG_PRINTLN(F("\n--- ALERTES ---"));
  DEBUG_PRINTF("Niveau: %s\n", alertLevelToString(systemState.alerts.currentLevel));
  DEBUG_PRINTF("Actives: %d\n", systemState.alerts.activeAlertCount);
  
  if (systemState.alerts.activeAlertCount > 0) {
    DEBUG_PRINTLN(F("Liste:"));
    for (uint8_t i = 0; i < systemState.alerts.activeAlertCount; i++) {
      Alert alert = systemState.alerts.alerts[i];
      DEBUG_PRINTF("  %d. %s - %s (%.1f)\n",
                   i + 1,
                   alertTypeToShortString(alert.type),
                   alertLevelToString(alert.level),
                   alert.value);
    }
  }
  
  // Performance
  DEBUG_PRINTLN(F("\n--- PERFORMANCE ---"));
  DEBUG_PRINTF("Loops: %lu\n", loopCount);
  unsigned long avgLoopTime = (millis() - loopStartTime) / loopCount;
  DEBUG_PRINTF("Temps loop moyen: %lu ms\n", avgLoopTime);
  DEBUG_PRINTF("RAM libre: %d bytes\n", freeRam());
  
  DEBUG_PRINTLN(F("====================================\n"));
}

/**
 * @brief Calcule la RAM libre disponible
 * @return Bytes de RAM libre
 */
int freeRam() {
  extern int __heap_start, *__brkval;
  int v;
  return (int) &v - (__brkval == 0 ? (int) &__heap_start : (int) __brkval);
}

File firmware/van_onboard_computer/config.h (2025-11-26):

/**
 * @file config.h
 * @brief Configuration centralisée du système Van Onboard Computer
 * @author Frédéric BAILLON
 * @version 0.1.0
 * @date 2024-11-26
 * 
 * @details
 * Fichier de configuration centralisé contenant :
 * - Adresses I2C de tous les périphériques
 * - Pins GPIO utilisées
 * - Seuils d'alerte (CO, GPL, tensions, températures)
 * - Intervalles d'acquisition
 * - Paramètres d'affichage
 */

#ifndef CONFIG_H
#define CONFIG_H

#include <Arduino.h>

// ============================================
// VERSION FIRMWARE
// ============================================
#define FIRMWARE_VERSION        "1.0.0"
#define FIRMWARE_DATE           "2024-11-26"

// ============================================
// CONFIGURATION MATÉRIELLE - ADRESSES I2C
// ============================================
#define I2C_BME280              0x76    ///< Capteur environnemental intérieur
#define I2C_MPU6050             0x68    ///< Accéléromètre/gyroscope
#define I2C_INA226_12V          0x40    ///< Surveillance rail 12V
#define I2C_INA226_5V           0x41    ///< Surveillance rail 5V
#define I2C_LCD                 0x27    ///< Écran LCD 20x4

// ============================================
// CONFIGURATION MATÉRIELLE - PINS GPIO
// ============================================
// Capteurs analogiques/numériques
#define PIN_MQ7                 A0      ///< Capteur CO (analogique)
#define PIN_MQ2                 A1      ///< Capteur GPL/fumée (analogique)
#define PIN_DS18B20             22      ///< Capteur température extérieure (OneWire)

// Encodeur rotatif KY040
#define PIN_ENCODER_CLK         2       ///< Encodeur CLK (interruption)
#define PIN_ENCODER_DT          3       ///< Encodeur DT (interruption)
#define PIN_ENCODER_SW          4       ///< Encodeur bouton poussoir

// Périphériques de sortie
#define PIN_BUZZER              25      ///< Buzzer piézoélectrique
#define PIN_WS2812B             6       ///< Bandeau LED WS2812B

// LCD déporté (optionnel, non implémenté v1.0)
#define PIN_DASHBOARD_TX        18      ///< UART2 TX vers Arduino Nano
#define PIN_DASHBOARD_RX        19      ///< UART2 RX depuis Arduino Nano

// ============================================
// CONFIGURATION WS2812B
// ============================================
#define LED_COUNT               8       ///< Nombre total de LEDs
#define LED_BRIGHTNESS          76      ///< Luminosité (0-255), 30% = 76

// Répartition des LEDs
#define LED_POWER_START         0       ///< LEDs 0-3 : Barre puissance
#define LED_POWER_COUNT         4
#define LED_CO                  4       ///< LED 4 : Indicateur CO
#define LED_GPL                 5       ///< LED 5 : Indicateur GPL
#define LED_VOLTAGE_12V         6       ///< LED 6 : État 12V
#define LED_VOLTAGE_5V          7       ///< LED 7 : État 5V

// ============================================
// SEUILS ALERTES - GAZ DANGEREUX
// ============================================
// MQ7 - Monoxyde de carbone (CO)
#define CO_THRESHOLD_INFO       50      ///< Info : détection faible (ppm)
#define CO_THRESHOLD_WARNING    200     ///< Warning : attention nécessaire (ppm)
#define CO_THRESHOLD_DANGER     400     ///< Danger : évacuation immédiate (ppm)

// MQ2 - GPL/Méthane
#define GPL_THRESHOLD_INFO      500     ///< Info : détection faible (ppm)
#define GPL_THRESHOLD_WARNING   1000    ///< Warning : attention nécessaire (ppm)
#define GPL_THRESHOLD_DANGER    3000    ///< Danger : évacuation immédiate (ppm)

// MQ2 - Fumée
#define SMOKE_THRESHOLD_INFO    1000    ///< Info : détection faible (ppm)
#define SMOKE_THRESHOLD_WARNING 1500    ///< Warning : attention nécessaire (ppm)
#define SMOKE_THRESHOLD_DANGER  2000    ///< Danger : évacuation immédiate (ppm)

// ============================================
// SEUILS ALERTES - ÉLECTRIQUES
// ============================================
// Rail 12V (batterie)
#define VOLTAGE_12V_MIN         10.5    ///< Minimum absolu (décharge profonde)
#define VOLTAGE_12V_WARNING     11.5    ///< Warning : batterie faible
#define VOLTAGE_12V_NOMINAL     12.0    ///< Nominal : au repos
#define VOLTAGE_12V_CHARGING    13.8    ///< En charge (alternateur)
#define VOLTAGE_12V_MAX         14.5    ///< Maximum admissible

// Rail 5V (électronique)
#define VOLTAGE_5V_MIN          4.5     ///< Minimum admissible
#define VOLTAGE_5V_NOMINAL      5.0     ///< Nominal
#define VOLTAGE_5V_MAX          5.5     ///< Maximum admissible

// Courants maximaux (alertes sur-courant)
#define CURRENT_12V_MAX         20.0    ///< Courant max rail 12V (A)
#define CURRENT_5V_MAX          3.0     ///< Courant max rail 5V (A)
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

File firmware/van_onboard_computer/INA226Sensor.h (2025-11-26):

/**
 * @file INA226Sensor.h
 * @brief Classe de gestion du capteur de courant/tension INA226
 * @author Frédéric BAILLON
 * @version 0.1.0
 * @date 2024-11-24
 * 
 * @details
 * Utilisable dans le programme de test et le programme principal.
 * Compatible avec la bibliothèque INA226Lib par Peter Buchegger.
 * Développé pour Arduino Mega R3.
 * 
 * Principes de conception :
 * - Support de plusieurs INA226 sur le même bus I2C (12V et 5V)
 * - Mesure tension, courant et puissance
 * - Configuration flexible (résolution, moyennage)
 * - Responsabilité unique : surveiller alimentation électrique
 */

#ifndef INA226_SENSOR_H
#define INA226_SENSOR_H

#include <Arduino.h>
#include <Wire.h>
#include <INA226.h>  // INA226Lib par Peter Buchegger

// ============================================
// CONFIGURATION MATÉRIELLE
// ============================================
#define INA226_I2C_ADDR_12V     0x40  ///< Adresse I2C rail 12V (A1=GND, A0=GND)
#define INA226_I2C_ADDR_5V      0x41  ///< Adresse I2C rail 5V (A1=GND, A0=VCC)

// Paramètres des Shunts
#define INA226_SHUNT_12V        0.002f  ///< Résistance shunt 12V en Ohms (2 mΩ)
#define INA226_SHUNT_5V         0.010f  ///< Résistance shunt 5V en Ohms (10 mΩ)

// Courants max calculés selon les shunts
// INA226 : V_shunt_max = ±81.92 mV
// I_max = V_shunt_max / R_shunt
#define INA226_MAX_CURRENT_12V  40.0f   ///< Courant max 12V : 81.92mV / 2mΩ = 40.96A
#define INA226_MAX_CURRENT_5V   8.0f    ///< Courant max 5V : 81.92mV / 10mΩ = 8.19A

#define INA226_UPDATE_INTERVAL  500     ///< Intervalle de mise à jour (ms)

// ============================================
// TYPES ET STRUCTURES
// ============================================
/**
 * @enum PowerRailType
 * @brief Type de rail d'alimentation
 */
enum class PowerRailType {
  RAIL_12V,     ///< Rail 12 volts
  RAIL_5V       ///< Rail 5 volts
};

/**
 * @struct INA226Data
 * @brief Structure contenant les mesures du capteur
 */
struct INA226Data {
  float busVoltage;         ///< Tension bus en V
  float shuntVoltage;       ///< Tension shunt en V
  float current;            ///< Courant en A
  float power;              ///< Puissance en W
  bool valid;               ///< Validité des mesures
  unsigned long timestamp;  ///< Timestamp de la mesure
};

/**
 * @enum INA226Status
 * @brief État du capteur
 */
enum class INA226Status {
  OK,                   ///< Fonctionnement normal
  NOT_INITIALIZED,      ///< Pas encore initialisé
  NOT_FOUND,            ///< Capteur non détecté sur I2C
  OVERFLOW,             ///< Dépassement capacité mesure
  UNDERVOLTAGE,         ///< Sous-tension détectée
  OVERCURRENT           ///< Sur-courant détecté
};

// ============================================
// DEFINITION CLASSE INA226Sensor
// ============================================
/**
 * @class INA226Sensor
 * @brief Classe de gestion du capteur INA226
 * 
 * Cette classe gère un capteur INA226 pour surveiller tension,
 * courant et puissance sur un rail d'alimentation.
 */
class INA226Sensor {
private:
  INA226 ina;                       ///< Instance librairie INA226
  PowerRailType railType;           ///< Type de rail surveillé
  uint8_t i2cAddress;               ///< Adresse I2C
  
  // Mesures actuelles
  float busVoltage;                 ///< Tension bus (V)
  float shuntVoltage;               ///< Tension shunt (V)
  float current;                    ///< Courant (A)
  float power;                      ///< Puissance (W)
  
  // Configuration
  float shuntResistance;            ///< Résistance shunt (Ω)
  float maxCurrent;                 ///< Courant max (A)
  
  // Seuils d'alerte
  float voltageMin;                 ///< Tension minimale (V)
  float voltageMax;                 ///< Tension maximale (V)
  float currentMax;                 ///< Courant maximal (A)
  
  // État
  bool initialized;                 ///< État initialisation
  INA226Status status;              ///< État actuel
  unsigned long lastUpdate;         ///< Timestamp dernière MAJ
  uint16_t updateInterval;          ///< Intervalle de mise à jour (ms)
  
  /**
   * @brief Vérifie si les mesures sont dans les limites
   * @return true si OK, false si dépassement
   */
  bool checkLimits() {
    bool ok = true;
    
    // Vérifier tension
    if (busVoltage < voltageMin) {
      status = INA226Status::UNDERVOLTAGE;
      ok = false;
    } else if (busVoltage > voltageMax) {
      status = INA226Status::OVERFLOW;
      ok = false;
    }
    
    // Vérifier courant
    if (current > currentMax) {
      status = INA226Status::OVERCURRENT;
      ok = false;
    }
    
    if (ok) {
      status = INA226Status::OK;
    }
    
    return ok;
  }
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

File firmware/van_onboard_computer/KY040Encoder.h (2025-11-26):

/**
 * @file KY040Encoder.h
 * @brief Classe de gestion de l'encodeur rotatif KY040
 * @author Frédéric BAILLON
 * @version 0.1.0
 * @date 2024-11-21
 * 
 * @details
 * Utilisable dans le programme de test et le programme principal.
 * 
 * Principes de conception :
 * - Gestion des rotations (CW/CCW) et du bouton poussoir
 * - Détection des changements avec debouncing
 * - Responsabilité unique : lire et traiter événements encodeur
 */

#ifndef KY040_ENCODER_H
#define KY040_ENCODER_H

#include <Arduino.h>

// ============================================
// CONFIGURATION
// ============================================
#define KY040_DEBOUNCE_DELAY    5     ///< Délai anti-rebond rotation (ms)
#define KY040_BUTTON_DEBOUNCE   50    ///< Délai anti-rebond bouton (ms)
#define KY040_LONG_PRESS_TIME   1000  ///< Durée appui long (ms)

// ============================================
// TYPES ET STRUCTURES
// ============================================
/**
 * @enum RotationDirection
 * @brief Direction de rotation de l'encodeur
 */
enum class RotationDirection {
  NONE = 0,         ///< Pas de rotation
  CLOCKWISE = 1,    ///< Rotation horaire (CW)
  COUNTER_CLOCKWISE = -1  ///< Rotation anti-horaire (CCW)
};

/**
 * @enum ButtonEvent
 * @brief Type d'événement bouton
 */
enum class ButtonEvent {
  NONE,           ///< Aucun événement
  PRESSED,        ///< Bouton appuyé
  RELEASED,       ///< Bouton relâché
  CLICKED,        ///< Clic court
  LONG_PRESS      ///< Appui long
};

/**
 * @struct EncoderData
 * @brief Structure contenant l'état de l'encodeur
 */
struct EncoderData {
  int32_t position;                 ///< Position actuelle
  RotationDirection lastDirection;  ///< Dernière direction
  ButtonEvent lastButtonEvent;      ///< Dernier événement bouton
  bool buttonPressed;               ///< État actuel du bouton
  unsigned long timestamp;          ///< Timestamp de la dernière MAJ
};

// ============================================
// DEFINITION CLASSE KY040Encoder
// ============================================
/**
 * @class KY040Encoder
 * @brief Classe de gestion de l'encodeur rotatif KY040
 * 
 * Cette classe gère un encodeur rotatif avec bouton poussoir intégré.
 * Elle détecte les rotations (CW/CCW) et les événements bouton.
 */
class KY040Encoder {
private:
  // Pins
  uint8_t pinCLK;               ///< Broche CLK (sortie A)
  uint8_t pinDT;                ///< Broche DT (sortie B)
  uint8_t pinSW;                ///< Broche SW (bouton)
  
  // État rotation
  int32_t position;             ///< Position courante
  volatile uint8_t lastStateCLK;     ///< Dernier état CLK
  volatile uint8_t lastStateDT;      ///< Dernier état DT
  volatile bool rotationDetected;    ///< Flag rotation détectée
  volatile RotationDirection lastDirection;  ///< Dernière direction
  unsigned long lastRotationTime;    ///< Timestamp dernière rotation
  
  // État bouton
  bool buttonState;             ///< État actuel du bouton
  bool lastButtonState;         ///< État précédent du bouton
  unsigned long lastButtonChange;    ///< Timestamp dernier changement
  unsigned long buttonPressTime;     ///< Timestamp début appui
  bool longPressDetected;       ///< Flag appui long détecté
  ButtonEvent lastButtonEvent;  ///< Dernier événement bouton
  
  // Configuration
  bool initialized;             ///< État initialisation
  bool reverseDirection;        ///< Inverser sens de rotation
  int32_t minPosition;          ///< Position minimale
  int32_t maxPosition;          ///< Position maximale
  bool limitEnabled;            ///< Activer limites position
  
  /**
   * @brief Lit l'état actuel des pins CLK et DT
   */
  void readEncoderState() {
    uint8_t clkState = digitalRead(pinCLK);
    uint8_t dtState = digitalRead(pinDT);
    
    // Détection de rotation (transition sur CLK)
    if (clkState != lastStateCLK) {
      unsigned long now = millis();
      
      // Anti-rebond
      if (now - lastRotationTime >= KY040_DEBOUNCE_DELAY) {
        lastRotationTime = now;
        
        // Déterminer direction
        if (clkState != dtState) {
          // Rotation horaire
          lastDirection = reverseDirection ? 
            RotationDirection::COUNTER_CLOCKWISE : 
            RotationDirection::CLOCKWISE;
          
          if (!limitEnabled || position < maxPosition) {
            position++;
          }
        } else {
          // Rotation anti-horaire
          lastDirection = reverseDirection ? 
            RotationDirection::CLOCKWISE : 
            RotationDirection::COUNTER_CLOCKWISE;
          
          if (!limitEnabled || position > minPosition) {
            position--;
          }
        }
        
        rotationDetected = true;
      }
    }
    
    lastStateCLK = clkState;
    lastStateDT = dtState;
  }
  
  /**
   * @brief Traite les événements du bouton
   */
  void processButton() {
    unsigned long now = millis();
    bool currentState = digitalRead(pinSW) == LOW;  // Actif bas
    
    // Anti-rebond
    if (now - lastButtonChange < KY040_BUTTON_DEBOUNCE) {
      return;
    }
    
    // Changement d'état détecté
    if (currentState != buttonState) {
      lastButtonChange = now;
      buttonState = currentState;
      
      if (buttonState) {
        // Bouton appuyé
        buttonPressTime = now;
        longPressDetected = false;
        lastButtonEvent = ButtonEvent::PRESSED;
      } else {
        // Bouton relâché
        unsigned long pressDuration = now - buttonPressTime;
        
        if (pressDuration >= KY040_LONG_PRESS_TIME) {
          lastButtonEvent = ButtonEvent::LONG_PRESS;
        } else {
          lastButtonEvent = ButtonEvent::CLICKED;
        }
      }
    }
    
    // Détection appui long en cours
    if (buttonState && !longPressDetected) {
      if (now - buttonPressTime >= KY040_LONG_PRESS_TIME) {
        longPressDetected = true;
        lastButtonEvent = ButtonEvent::LONG_PRESS;
      }
    }
  }
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

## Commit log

2025-11-26 feat: Initial implementation v0.1.0 - Core system
    - Add configuration file with all hardware constants and thresholds
    - Add system data structures (modes, screens, alerts, sensors state)
    - Add sensor manager (7 sensors with non-blocking acquisition)
    - Add alert system (hierarchical alerts with buzzer control)
    - Add LED manager (WS2812B 8-LED bar with power/gas/voltage indicators)
    - Add display manager (6 screens with rotary encoder navigation)
    - Add main program (orchestrates all modules)
    Features:
    - Environment monitoring (BME280, DS18B20)
    - Power monitoring (INA226 12V/5V)
    - Gas safety (MQ7 CO, MQ2 GPL/smoke with 3min preheat)
    - Level monitoring (MPU6050 with calibration)
    - Hierarchical a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
    [BME280Sensor.h, Buzzer.h, DS18B20Sensor.h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]
2025-11-28 Add KiCad project for Van Onboard Computer schematics
    [van-obc.kicad_pcb, van-obc.kicad_sch]
2025-11-30 Add KiCad schematics for Van Onboard Computer (v1.0)
    [Display_And_UI.kicad_sch, MCU_Arduino_Mega.kicad_sch, Power_Input.kicad_sch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]
2025-12-10 fix(tests): Corrections majeures KY040, BME280, MPU6050
    - KY040 v2.1.0: Fix comptage + anti-rebond capacitif
    - BME280 v1.0.1: Fix begin() avec &Wire
    - MPU6050 v2.0.0: Simplification (acc only, dérive <2°)
    - Ajout diagnostic_bme280.ino + CHANGELOG
    Tests: 6/11 validés (55%)
    [Display_And_UI.kicad_sch, MCU_Arduino_Mega.kicad_sch, Power_Input.kicad_sch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]
2025-12-10 add(test): Ruban LEDs
    - WS2812B v2.0.0: Test matériel et scénarios de mise en oeuvre
    Tests: 7/11 validés (63%)
2025-12-11 add(test): BUZZER
    - BUZZER v1.0.0: Test matériel & fix: préfixe appel fonction tone et notone
    Tests: 8/11 validés (72%)
    [Buzzer.h, test_buzzer.ino]

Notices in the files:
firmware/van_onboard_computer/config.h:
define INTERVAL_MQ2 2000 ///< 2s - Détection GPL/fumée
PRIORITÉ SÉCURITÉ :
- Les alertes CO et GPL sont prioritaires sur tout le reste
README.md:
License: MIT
